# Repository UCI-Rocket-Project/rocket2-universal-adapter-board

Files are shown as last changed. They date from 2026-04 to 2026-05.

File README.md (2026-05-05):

## rocket2's universal adapter board for sensors
Converts a suite of sensors inputs into a female DSUB adapter  
  
More information on design: [Click Here](https://uci-rocket-project.github.io/rocket2-overview/standardized_connectors/)  

## CAD  


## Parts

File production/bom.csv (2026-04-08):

Designator | Footprint | Quantity | Value | LCSC Part #
D1 | D_SOD-123 | 1 | ~27V
F1 | Fuseholder_Blade_Mini_Keystone_3568 | 1 | 1A
J2 | Pad_Socket 9.4mm_MiniDIN | 1 | Conn_01x04_Socket
J3 | Pad_Socket 16AWG_Solenoid_Wires | 1 | Conn_01x02_Socket
J4 | PinHeader_1x04_P2.54mm_Vertical | 1 | Conn_01x04_Socket
J5 | Connector_VGA_Vertical | 1 | DSUB_15pin/VGA Veritical Female
R1, R2 | 0603 | 2 | 0 | 0603WAJ0000T5E
VR1 | Potentiometer P160KNPD4FC20B10K | 1 | 10k | P160KNPD-4FC20B10K

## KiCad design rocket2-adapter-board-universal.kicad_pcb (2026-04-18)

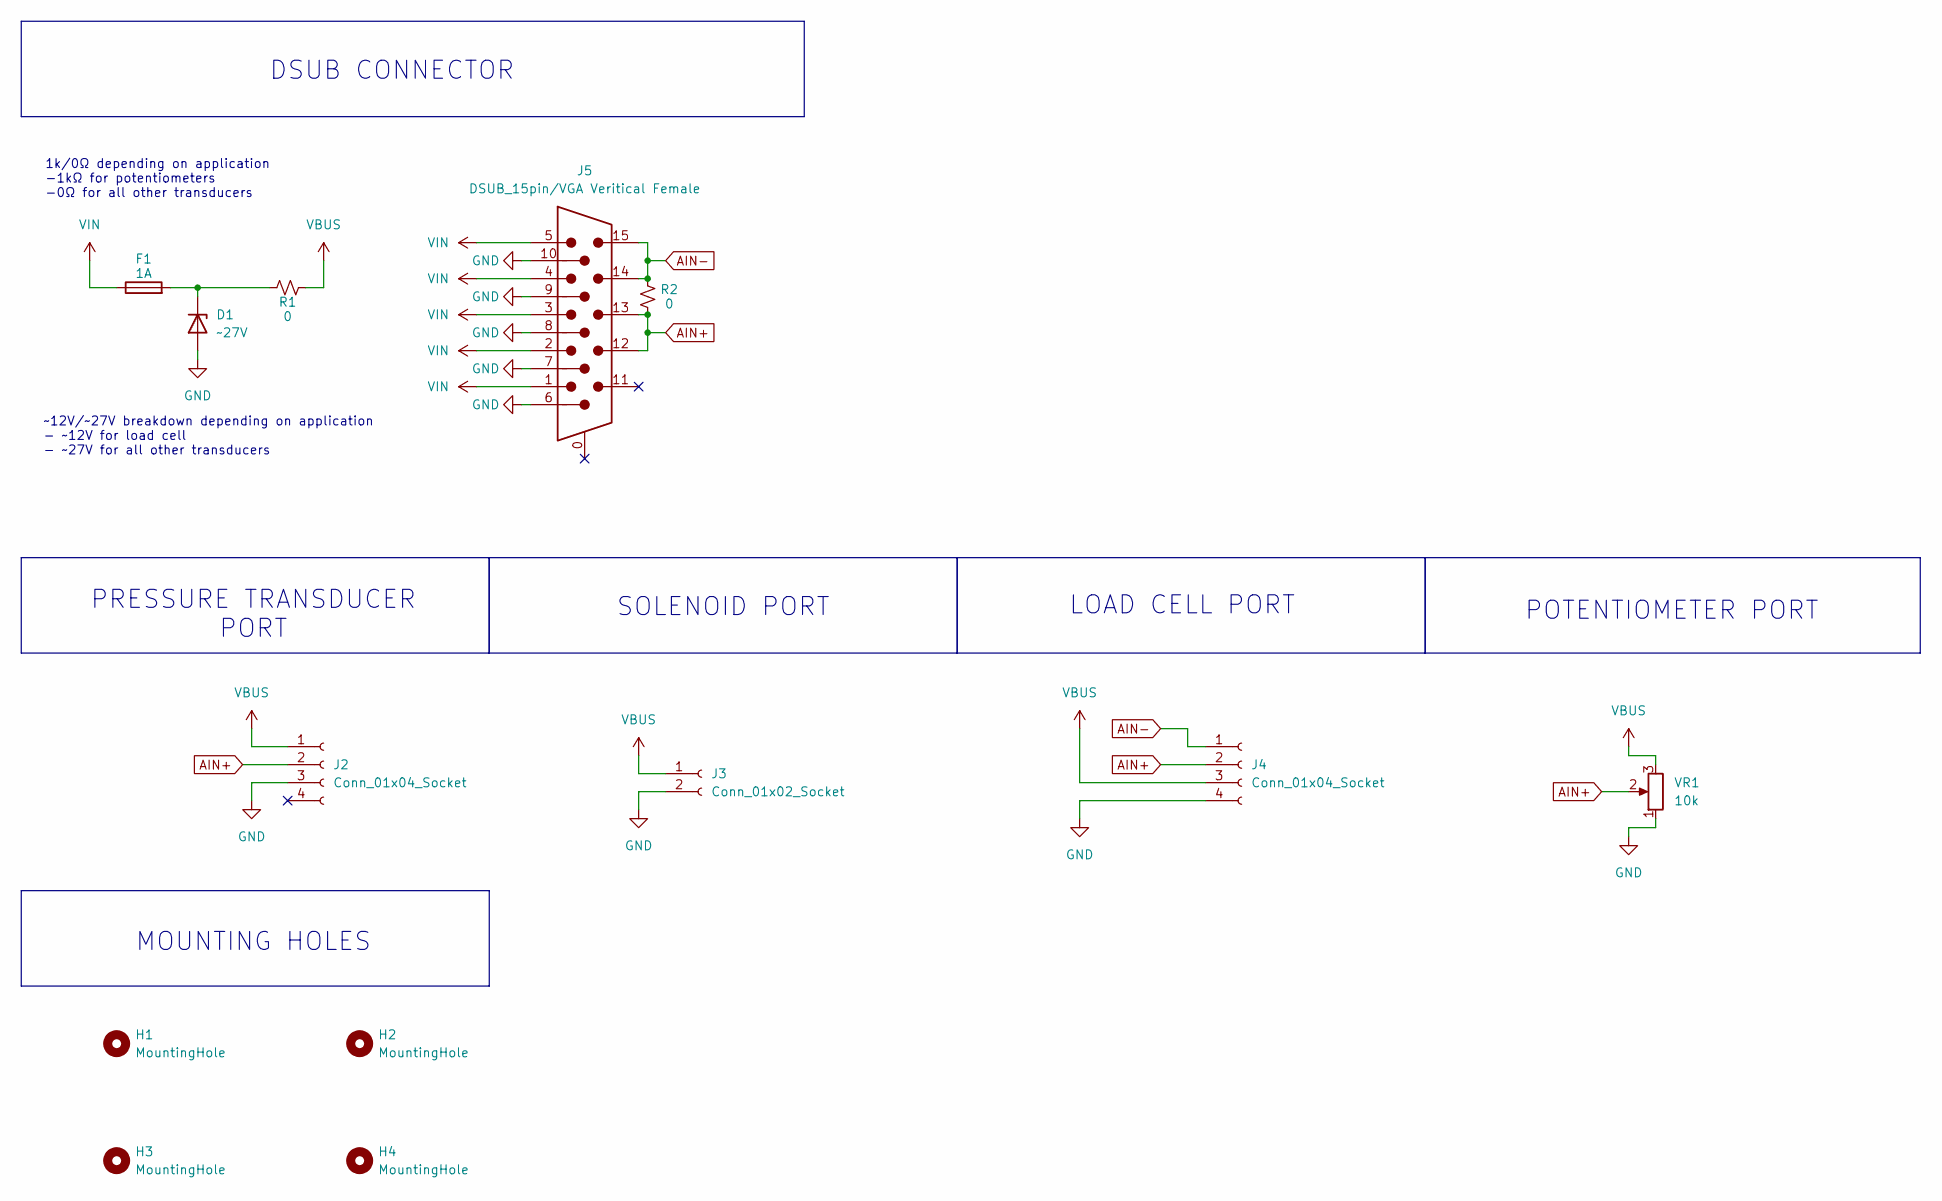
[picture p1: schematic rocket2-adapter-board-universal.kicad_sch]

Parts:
D1: ~27V; D_SOD-123
F1: 1A; Fuseholder_Blade_Mini_Keystone_3568
H1: MountingHole; MountingHole_3.2mm_M3_DIN965_Pad
H2, H3, H4: MountingHole; MountingHole_3.2mm_M3_ISO7380_Pad
J2: Conn_01x04_Socket; Pad_Socket 9.4mm_MiniDIN
J3: Conn_01x02_Socket; Pad_Socket 16AWG_Solenoid_Wires
J4: Conn_01x04_Socket; PinHeader_1x04_P2.54mm_Vertical
J5: DSUB_15pin/VGA Veritical Female; Connector_VGA_Vertical
R1, R2: 0; R_0603_1608Metric; MPN 0603WAJ0000T5E
VR1: 10k; Potentiometer P160KNPD4FC20B10K; MPN P160KNPD-4FC20B10K

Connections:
AIN+: J2.2, J4.2, J5.12, J5.13, R2.2, VR1.2
AIN-: J4.1, J5.14, J5.15, R2.1
GND: D1.2 (A), J2.3, J3.2, J4.4, J5.6, J5.7, J5.8, J5.9, J5.10, VR1.1
unnamed: D1.1 (K), F1.2, R1.2
VBUS: J2.1, J3.1, J4.3, R1.1, VR1.3
VIN: F1.1, J5.1, J5.2, J5.3, J5.4, J5.5

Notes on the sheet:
PRESSURE TRANSDUCER PORT
POTENTIOMETER PORT
DSUB CONNECTOR
SOLENOID PORT
MOUNTING HOLES
~12V/~27V breakdown depending on application - ~12V for load cell - ~27V for all other transducers
LOAD CELL PORT
1k/0Ω depending on application -1kΩ for potentiometers -0Ω for all other transducers

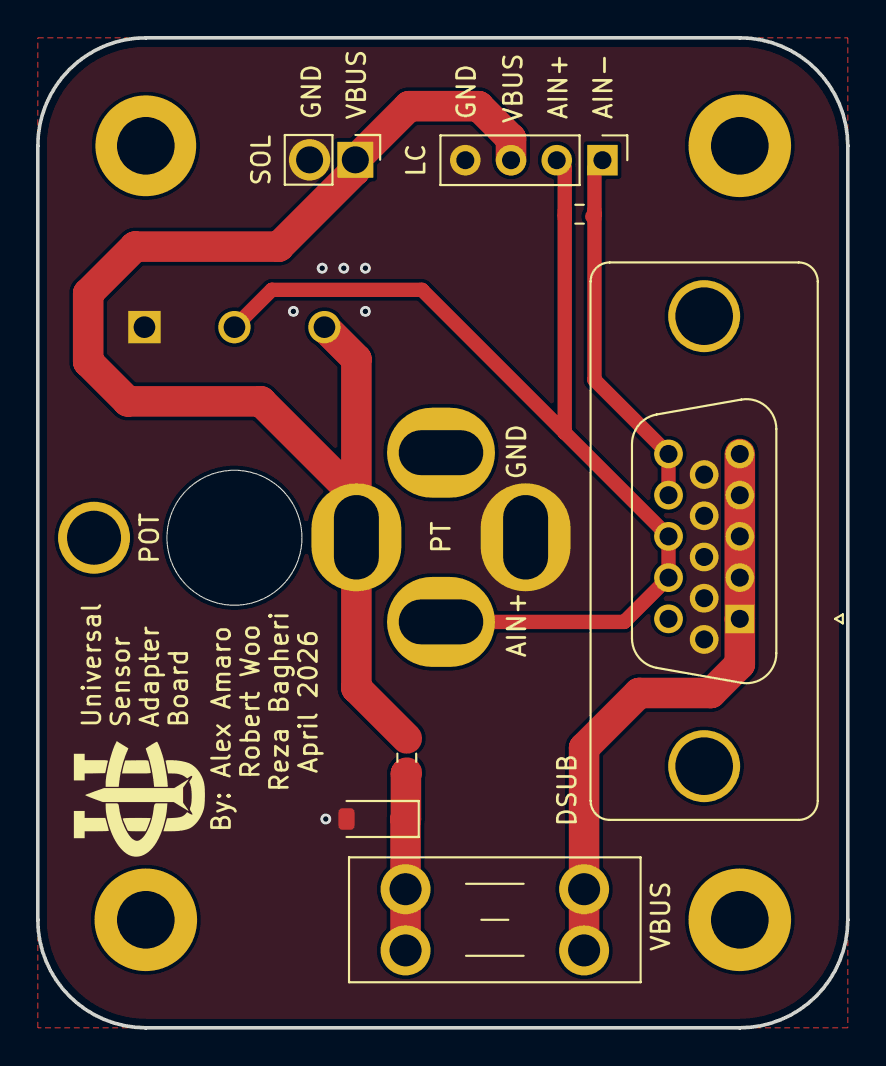
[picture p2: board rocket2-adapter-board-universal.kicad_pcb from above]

Board: 2 copper layers, 45.0 x 55.0 mm, 13 parts (1 on the bottom side), 6 nets.

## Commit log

2026-03-26 Prelim Schematic & Layout
    DSUB and GX Connector Only
    [733910070.stp, AM-K-PCB.step, BGA9_BMM350_BOS.step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]
2026-03-26 Quick Fix: Unconnected Pad
    Added routing to a disconnected pad on pulldown pins
    [rocket2-adapter-board-universal.kicad_pcb]
2026-04-02 BOM Generation Available + Standard KiCad Library
    Added webpages for JLCPCB pre-assembly BOM. Added new standardized KiCAD library.
    [GX-16.STEP, SOIC_3553A_TP1_F_TOS.step, rocket2-adapter-board-universal.csv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]
2026-04-02 Updated R2 Purchase Link
    [rocket2-adapter-board-universal.kicad_sch]
2026-04-02 Corrected R2 Link
    [rocket2-adapter-board-universal.kicad_sch]
2026-04-03 Layout Update
    [GX16-4.stp, GX16.STEP, rocket2-adapter-board-universal.csv]
2026-04-03 Quick Silkscreen Fix
    [rocket2-adapter-board-universal.kicad_pcb]
2026-04-03 Layout Update 2 + DSUB & Footprint Fixes
    [rocket2-adapter-board-universal.csv, rocket2-adapter-board-universal.kicad_pcb, rocket2-adapter-board-universal.kicad_sch]
2026-04-03 Layout Return Paths Fix
    Streamlined GND return paths
    [rocket2-adapter-board-universal.kicad_pcb]
2026-04-05 Layout Update 3 + Schematic Links & DSUB Update
    Added R2 to bridge AIN+ and AIN-
    [rocket2-adapter-board-universal.kicad_pcb, rocket2-adapter-board-universal.kicad_sch]
2026-04-06 Layout Update 4: NC pins, PT and Solenoid pad fixes
    [rocket2-adapter-board-universal.kicad_pcb, rocket2-adapter-board-universal.kicad_sch]
2026-04-07 Layout Update 5: Part spacing, Footprints, and Models
    [Potentiometer P160KNPD4FC20B10K.stp, rocket2-adapter-board-universal.kicad_pcb, rocket2-adapter-board-universal.kicad_sch]
2026-04-07 PT Footprint Update
    [rocket2-adapter-board-universal.kicad_pcb]
2026-04-08 PT Footprint Update 2
    Adjusted thickness to 1mm
    [rocket2-adapter-board-universal.kicad_pcb]
2026-04-08 Final PT Footprint Update
    Added an extra 1mm to all tolerances
    [rocket2-adapter-board-universal.kicad_pcb]
2026-04-08 Layout Update 6: Updated PT footprint, Silkscreen labels, M3s
    [rocket2-adapter-board-universal.kicad_pcb, rocket2-adapter-board-universal.kicad_sch]
2026-04-08 Ready for purchasing
    [733910070.stp, AM-K-PCB.step, BGA9_BMM350_BOS.step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]
2026-04-08 Repositioned things so it would fit better
    [rocket2-adapter-board-universal.kicad_pcb]
2026-04-18 Updated for order
    [designators.csv, positions.csv, rocket2-adapter-board-universal.kicad_pcb]
2026-05-05 Fixed resistor value/comments for POTs config
    [rocket2-adapter-board-universal.kicad_sch]
2026-05-05 Update README with project details and CAD image
    Added project overview and CAD image to README.
